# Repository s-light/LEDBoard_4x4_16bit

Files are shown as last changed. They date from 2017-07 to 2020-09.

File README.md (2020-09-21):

<!--lint disable maximum-line-length-->
<!--lint disable list-item-spacing-->
<!--lint disable list-item-indent-->

# LED-Board 4x4 16bit
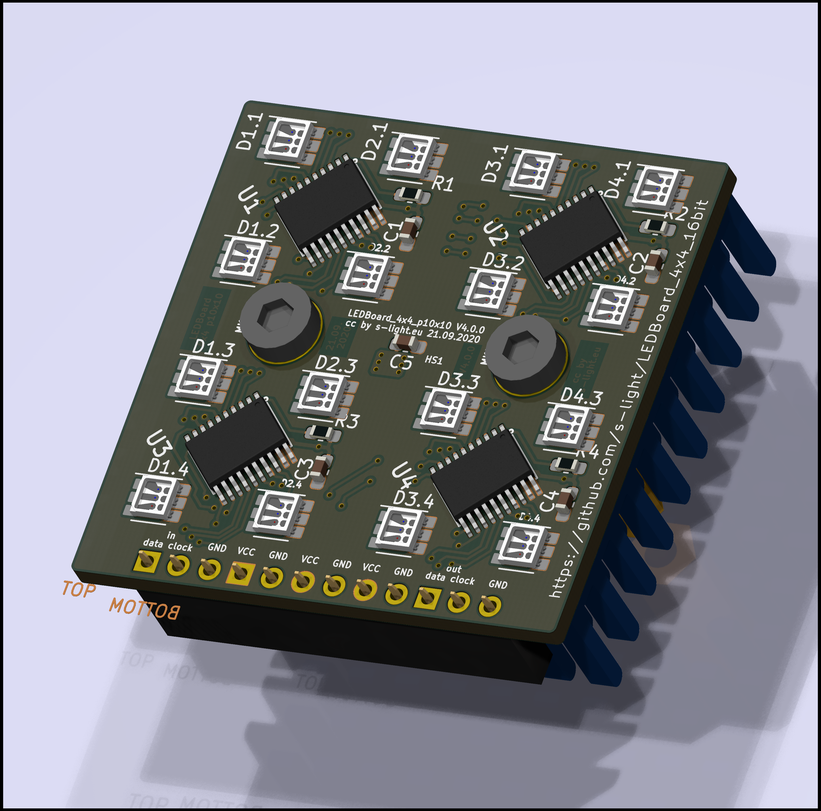
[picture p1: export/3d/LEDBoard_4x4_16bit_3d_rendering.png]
LED-Board front


a LED-Matrix Board that can be combined seamlessly to bigger areas.  
It uses the [TI TLC5971](http://www.ti.com/product/TLC5971) Constant-Current LED-Driver Chip with 16bit dimming resolution.  

The [original](https://github.com/s-light/LEDBoard_4x4_16bit/tree/Nichia_NSSM032A) LED-footprint was for [Nichia NSSM032A](http://www.nichia.co.jp/en/product/led_product_data.html?type=%27NSSM032A%27) RGB-LED.
Back in 2017 on of the brightest *low power* SMD LEDs in this size -
They are only available as full reel directly from Nichia.

so there is a [second branch](https://github.com/s-light/LEDBoard_4x4_16bit/tree/Nichia_NSSM124D) with the LED-Type changed to [Nichia NSSM124D](http://www.nichia.co.jp/en/product/led_product_data.html?type=%27NSSM124D%27) -
these are [available as cut-tape from an distributor](http://www.leds.de/en/Ordinary-LEDs/SMD-LEDs/Nichia-SMD-LED-RGB-NSSM124DT.html).

latest addition is a [branch with TLC5971*PWP* driver chips](https://github.com/s-light/LEDBoard_4x4_16bit/tree/TLC5971PWP) -
this is the same chip but in an HTSSOP-20 housing -
that is easier to solder by hand.
--> no hot air / reflow oven necessary, but recommend.

## Project-Status
- received first Batch ([Release V1.0.0](https://github.com/s-light/LEDBoard_4x4_16bit/releases/tag/v1.0))
- received second Batch ([Release V3.0.1](https://github.com/s-light/LEDBoard_4x4_16bit/tree/v3.0.1))
- 11 PCB's assembled  
  10 working :sun_with_face:  
  first solder board not working - has a short between VCC and GND (to be checked)
- all needed heavy rework: stencil has to big openings - this gives a bunch of bridges at QFN 0,5mm Pin-Pitch IC's
- had some problems with the first reflow oven used - you need enough heat from the bottom to solder correctly.
- made some picture from first assembly: [gallery](./doc/gallery.md)
- ~~fix pads that are to small for hand-soldering~~ done
- ~~order updated PCB's~~ done
- ~~solder some more boards~~ done (total: ~60)
- ~~order screws at [Wegertseder](https://www.wegertseder.com/ArticleDetails.aspx?AKNUM=2588)~~ done
- updated KiCad files to new version.

### TODO
- order Heat Sink with machining and Thermal Foil from [Fischer Elektronik](http://www.fischerelektronik.de/web_fischer/de_DE/K%C3%BChlk%C3%B6rper/B01/K%C3%BChlk%C3%B6rper%20f%C3%BCr%20PGA/PR/ICKPGA14x14x12_/$productCard/parameters/index.xht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)
- add some more mounting layouts to [LEDBoard_Layouts](https://github.com/s-light/LEDBoard_Layouts)
- take some more pictures

## Technical Information
there are groups of 4 LEDs that are controlled by one TLC5971.  
every controller chip has 12 ConstantCurrent outputs. so every LED is controllable individual.

you need to create a mapping to linearize the order:  

| X/Y | 0 | 1 | 2 | 3 |
| :---- | :--- | :--- | :--- | :--- |
| **0** | IC1 LED1 | IC1 LED2 | IC2 LED1 | IC2 LED2 |
| **1** | IC1 LED3 | IC1 LED4 | IC2 LED3 | IC2 LED4 |
| **2** | IC3 LED1 | IC3 LED2 | IC4 LED1 | IC4 LED2 |
| **3** | IC3 LED3 | IC3 LED4 | IC4 LED3 | IC4 LED4 |

example for c++ / arduino
```c++
const uint8_t channel_position_map[4][4] = {
    { 0,  1,  4,  5},
    { 2,  3,  6,  7},
    { 8,  9, 12, 13},
    {10, 11, 14, 15},
};
```

### HW
- PCB size: 40x40x18mm
- pixel-pitch: 10mm
- 3.8V..5.5V
- <= 1A (maximum)

### BOM
there is the raw exported BOM at [export/BOM/LEDBoard_4x4_16bit_BOM.csv](export/BOM/LEDBoard_4x4_16bit_BOM.csv) and an modified LibreOffice Calc file with ordering and Price calculations at [doc/LEDBoard_4x4_16bit_PriceCalculation_Ordering](doc/LEDBoard_4x4_16bit_PriceCalculation_Ordering.csv) (link points to exported csv as preview)

### controlling

#### Micro Controller / Arduino
there are some Arduino Libraries out there that can generate the correct protocol.
My Favorite is [ulrichstern/Tlc59711](https://github.com/ulrichstern/Tlc59711)

i have made a [simple arduino sketch](https://github.com/s-light/LEDBoard_4x4_16bit_HWTest) that uses the mentioned library to test the Boards during production.

#### embedded linux boards
Additionally you can use a embedded Linux board with an SPI output to drive them.
I have successfully implemented the protocol in my fork of OLA.
(TODO: Link and explain OLA setup)

there are also other python libraries out there.
(TODO: test some of theme and link here)

### power & signal connections
theoretically calculate with about 1A@5V for every Board.
Supply Voltage (VCC) should be 3,8V..5,5V - If possible use the lower end. so no extra heat is generated in the driver IC.

for the control-signal there are an input and output 3pin 2,54mm connector:
1. Data
1. Clock
1. GND

for the power there are 3x2pin 2,54mm connector positions.
so you could daisy-chain power also - but be aware the pcb-traces can handle an absolute maximum of 3,5A. So i would recommend only 1 or maximum 2 daisy-chained boards.

## KiCad Version
```text
Application: KiCad

Version: 5.99.0-unknown-652a59b78~104~ubuntu20.04.1, release build

Libraries:
	wxWidgets 3.0.4
	libcurl/7.68.0 OpenSSL/1.1.1f zlib/1.2.11 brotli/1.0.7 libidn2/2.2.0 libpsl/0.21.0 (+libidn2/2.2.0) libssh/0.9.3/openssl/zlib nghttp2/1.40.0 librtmp/2.3

Platform: Linux 5.4.0-48-generic x86_64, 64 bit, Little endian, wxGTK

Build Info:
	Date: Sep 16 2020 10:16:55
	wxWidgets: 3.0.4 (wchar_t,wx containers,compatible with 2.8) GTK+ 3.24
	Boost: 1.71.0
	OCE: 6.9.1
	Curl: 7.68.0
	ngspice: 31
	Compiler: GCC 9.3.0 with C++ ABI 1013

Build settings:
	KICAD_SCRIPTING=ON
	KICAD_SCRIPTING_MODULES=ON
	KICAD_SCRIPTING_PYTHON3=ON
	KICAD_SCRIPTING_WXPYTHON=ON
	KICAD_SCRIPTING_WXPYTHON_PHOENIX=ON
	KICAD_SCRIPTING_ACTION_MENU=ON
	BUILD_GITHUB_PLUGIN=ON
	KICAD_USE_OCE=ON
	KICAD_SPICE=ON

```

## License
<!-- License info -->
<a rel="license" href="http://creativecommons.org/licenses/by/4.0/">
    
</a><br />
<span xmlns:dct="http://purl.org/dc/terms/" property="dct:title">
    LEDBoard_4x4_16bit
</span>
by
<a xmlns:cc="http://creativecommons.org/ns#" href="https://github.com/s-light/LEDBoard_4x4_16bit" property="cc:attributionName" rel="cc:attributionURL">
    Stefan Krüger (s-light)
</a>
is licensed under a
<a rel="license" href="http://creativecommons.org/licenses/by/4.0/">
    Creative Commons Attribution 4.0 International License
</a>.

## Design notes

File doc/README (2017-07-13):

# documentation

contains Schematic and Board in SVG & PDF version.
+ additional documentation

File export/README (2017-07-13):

# export

contains gerber files and Layer-SVGs and Layer-PDFs

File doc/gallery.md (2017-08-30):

# assembly
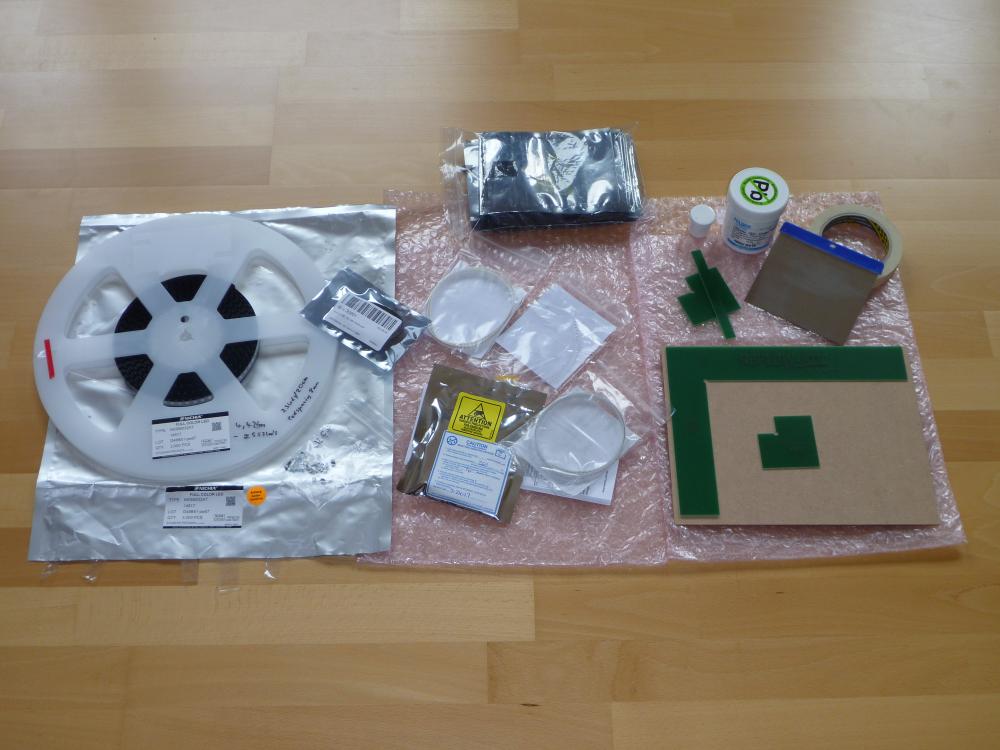
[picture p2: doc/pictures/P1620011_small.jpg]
parts

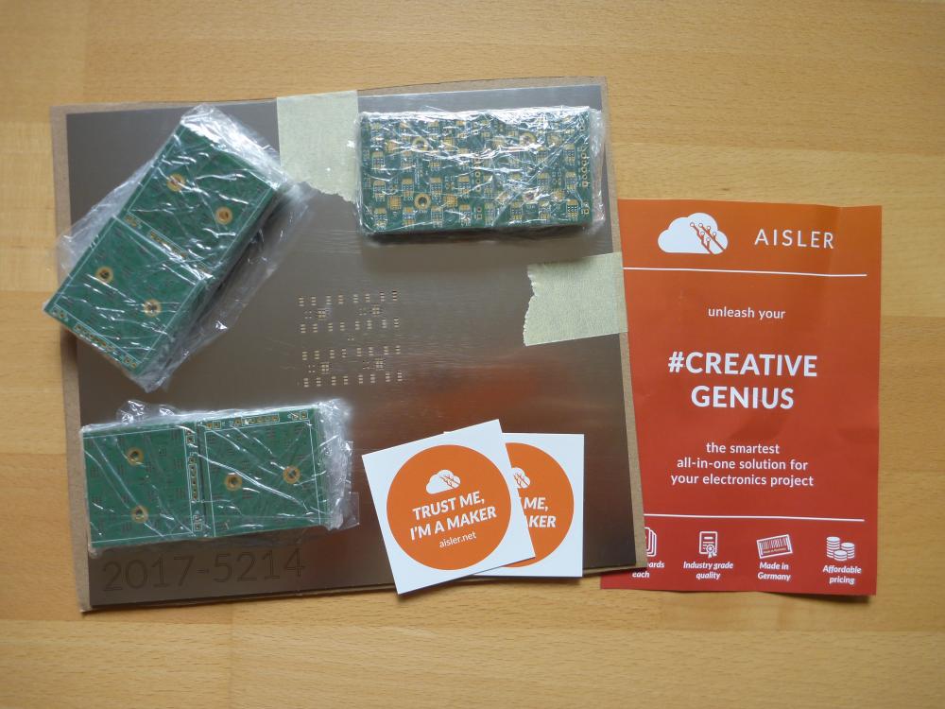
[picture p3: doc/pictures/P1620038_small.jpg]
PCBs

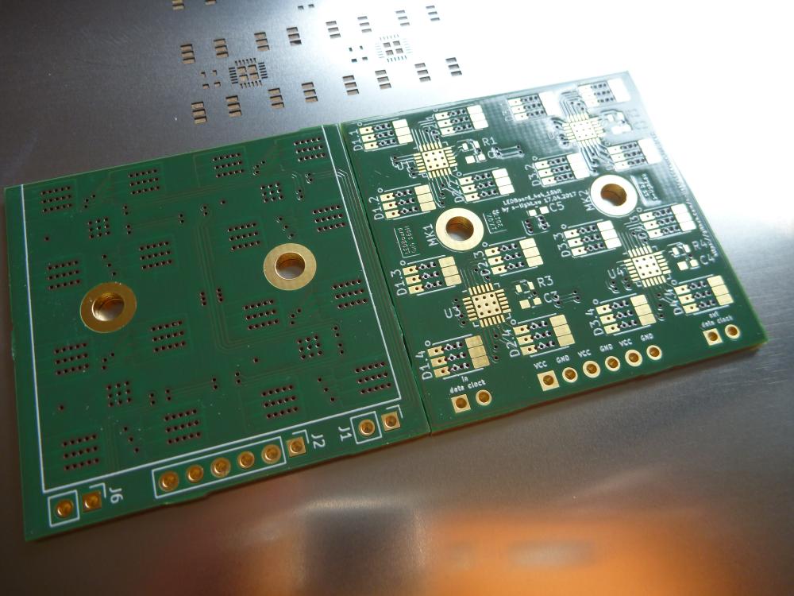
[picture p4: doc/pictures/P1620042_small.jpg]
PCBs details

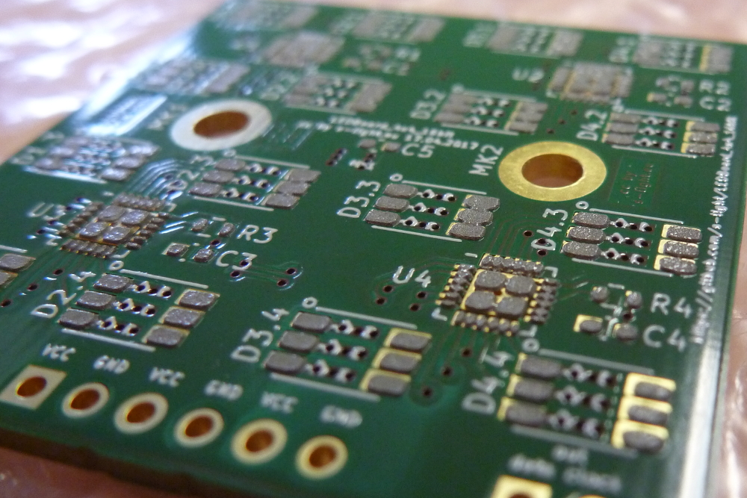
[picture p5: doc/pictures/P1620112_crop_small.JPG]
solderpaste details

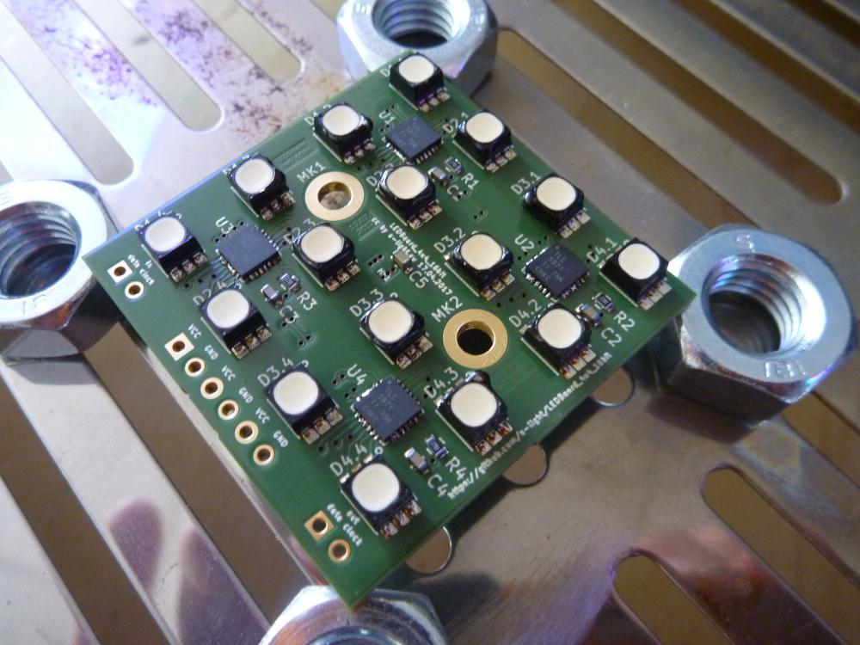
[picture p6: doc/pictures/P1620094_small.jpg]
reflow (a little hot :-(

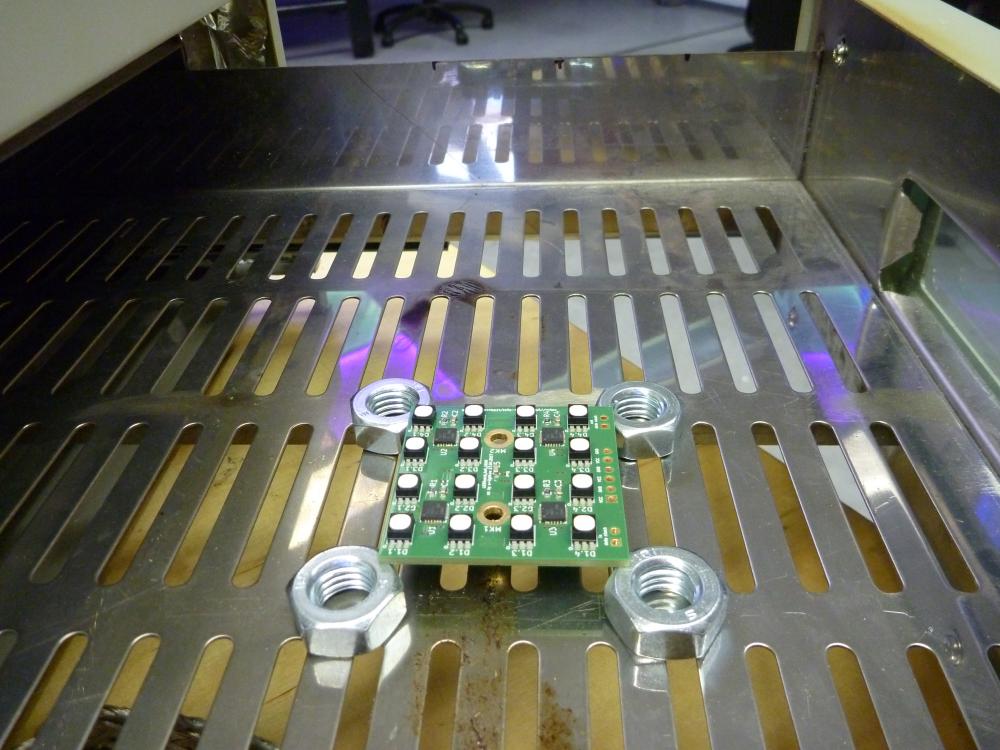
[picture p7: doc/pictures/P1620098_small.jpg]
reflow position in oven


## it works :-)
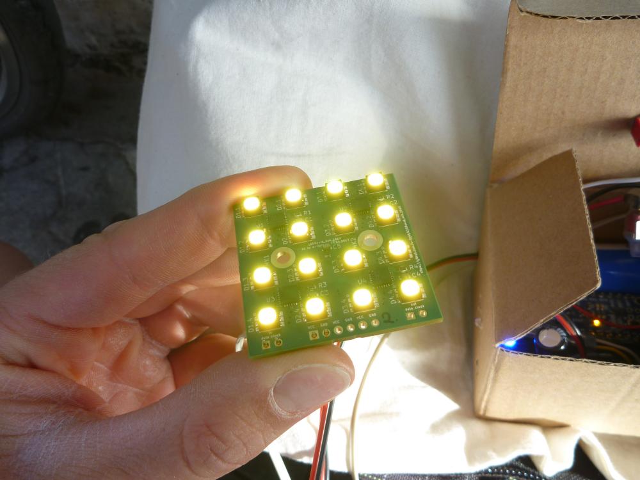
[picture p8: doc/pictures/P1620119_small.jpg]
test run yellow

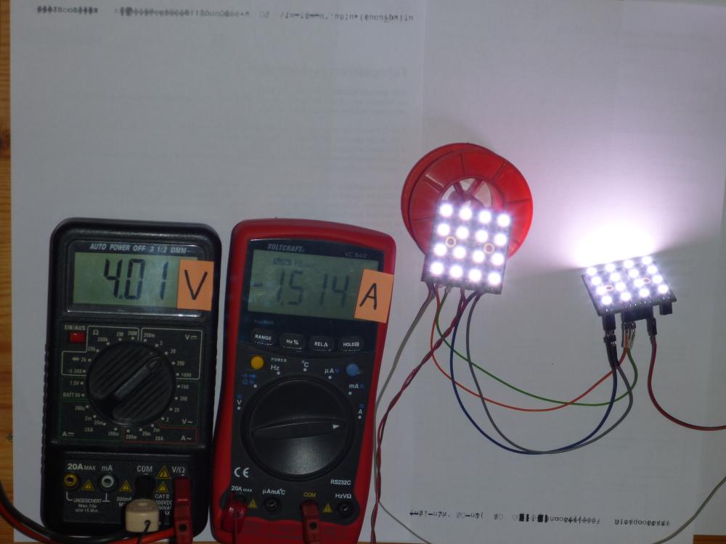
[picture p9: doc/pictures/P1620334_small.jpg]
two pcbs chained


(hover over the picture)
<style media="screen">
.specialimage {
    display: block;
    position: relative;
    z-index: 100;
}
.pic {
    display: block;
    position: absolute;
    top:0;
    left:0;
}
.specialimage .old {
    opacity: 1;
    transition: opacity 0.5s;
}
.specialimage:hover .old {
    opacity: 0;
    transition: opacity 0.5s;
}
</style>
<div class="specialimage">
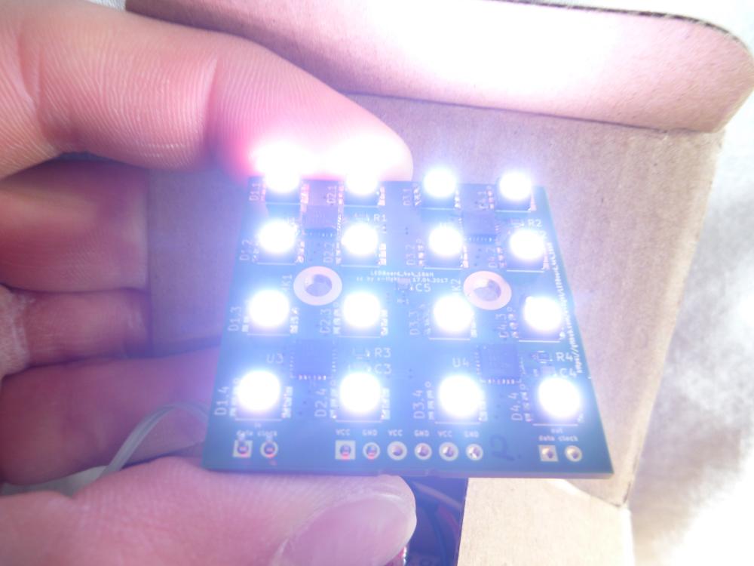
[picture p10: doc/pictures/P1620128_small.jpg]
    
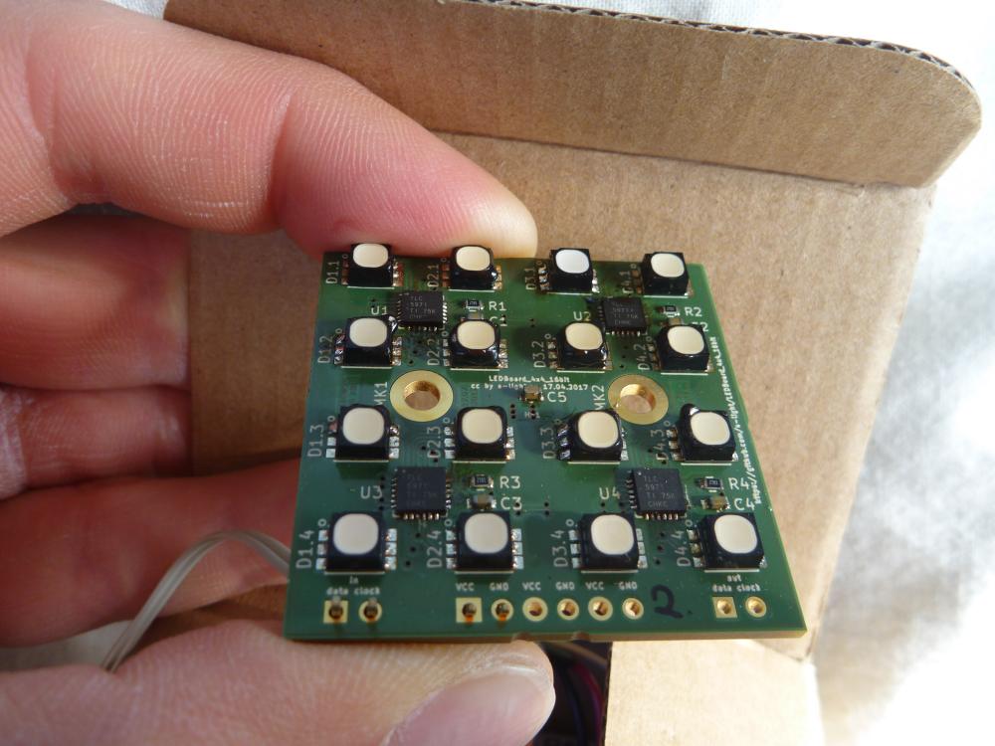
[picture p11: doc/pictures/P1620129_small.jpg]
    
</div>

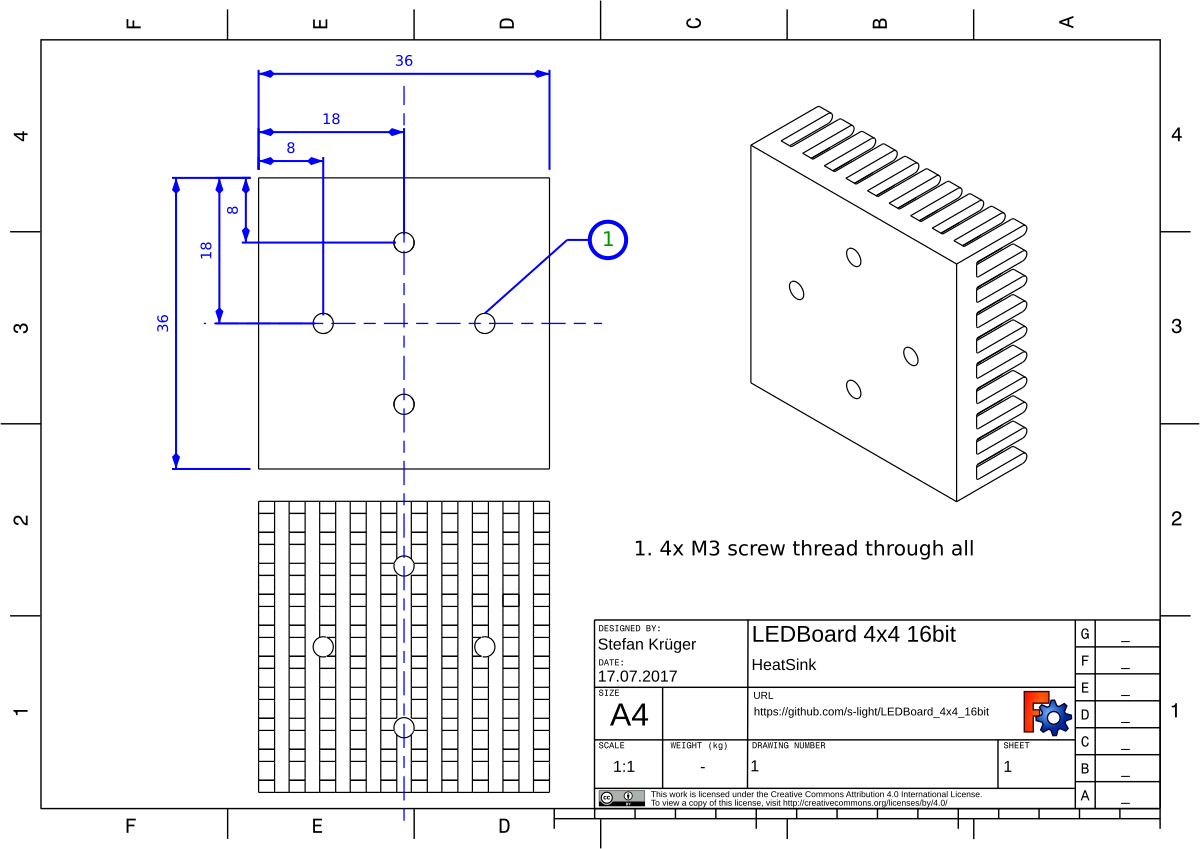
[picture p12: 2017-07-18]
parts/mechanical/HeatSink_drawing.png

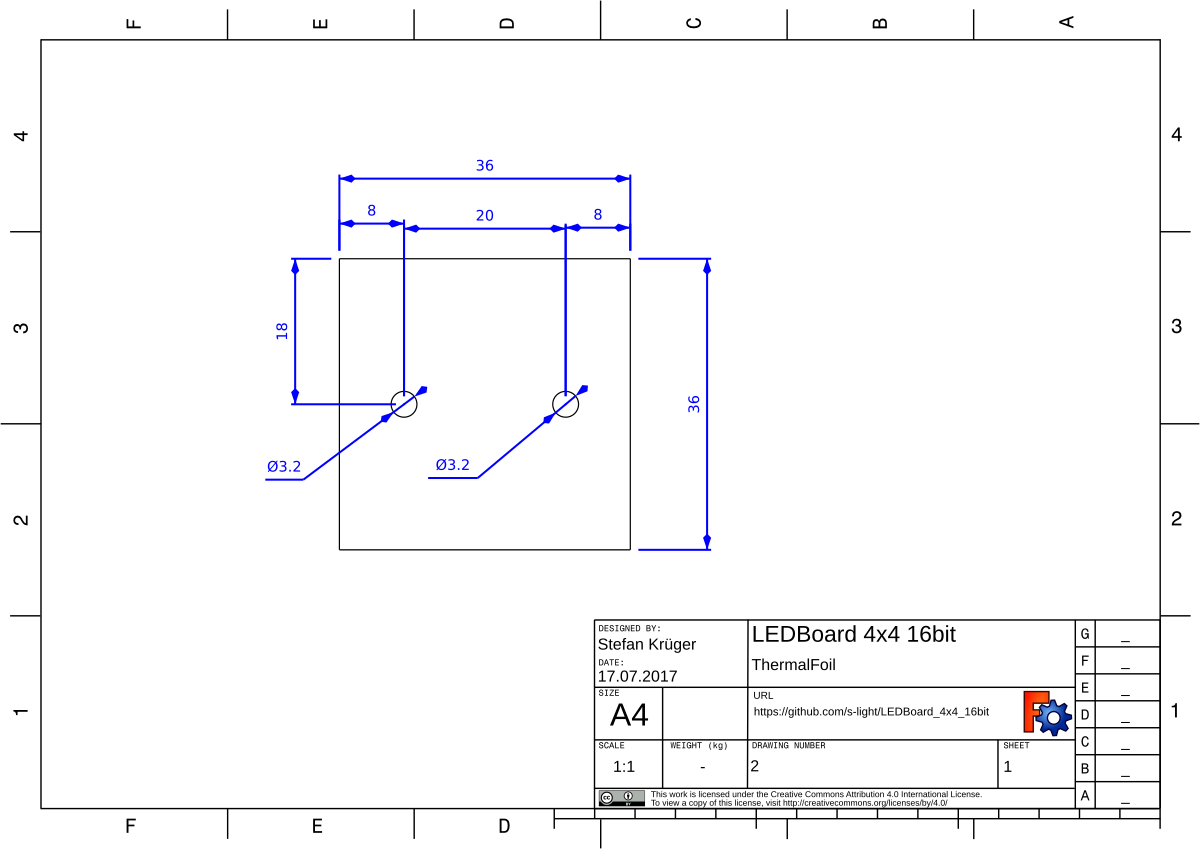
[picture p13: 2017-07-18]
parts/mechanical/ThermalFoil_drawing.png

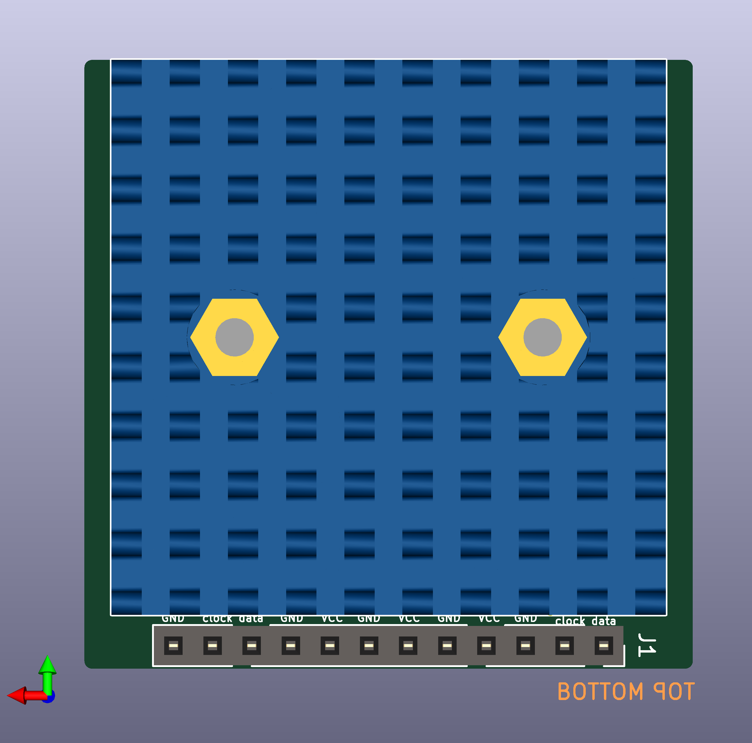
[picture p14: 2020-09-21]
export/3d/LEDBoard_4x4_16bit_back_wHeatSink.png

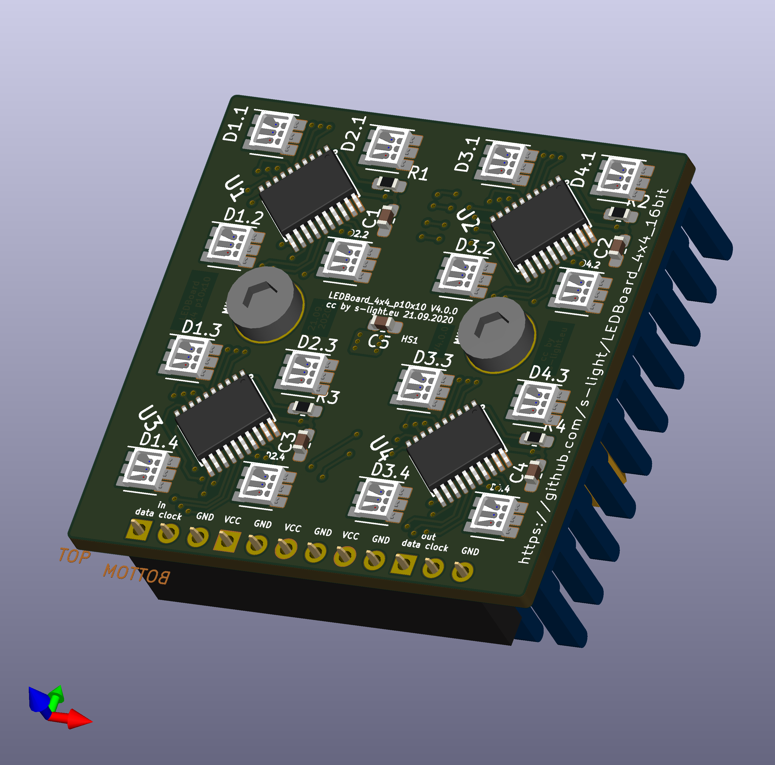
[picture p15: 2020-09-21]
export/3d/LEDBoard_4x4_16bit_3d.png

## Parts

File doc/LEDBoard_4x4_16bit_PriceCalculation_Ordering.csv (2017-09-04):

Reference | Quantity | Value | Footprint | Manufacture | Part | Manufacture URL | Distributor / shop | order number | price | Single Board Price | Min quantity For board count | package Size | Order Quantity | price sum
C1 C2 C3 C4 | 4 | 100nF | Capacitors_SMD:C_0603 | Murata | GRM188R71H104KA93D |  | mouser | 81-GRM39X104K50D | 0,019 € | 0,08 € | 12 | 1 | 15 | 0,29 €
C5 | 1 | 47uF 6.3V | Capacitors_SMD:C_0603 | Murata | ZRB18AR60J476ME01L |  | mouser | 81-ZRB18AR60J476ME1L | 0,349 € | 0,35 € | 3 | 1 | 5 | 1,75 €
D1.1 D1.2 D1.3 D1.4 D2.1 D2.2 D2.3 D2.4 D3.1 D3.2 D3.3 D3.4 D4.1 D4.2 D4.3 D4.4 | 16 | LED_1.1 .. LED_4.4 | nichia:LED_NSSM124_wViaHeatSinkBig | Nichia | NSSM124D |  | Lumitronix | 30201 | 0,890 € | 14,24 € | 48 | 1 | 50 | 44,50 €
HS1 | 1 | Heatsink | Oddities:Dummy_Empty | Fischer Elektronik | 10037097 | http://www.fischerelektronik.de/web_fischer/de_DE/K%C3%BChlk%C3%B6rper/B01/K%C3%BChlk%C3%B6rper%20f%C3%BCr%20PGA/PR/ICKPGA14x14x12_/$productCard/parameters/in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 | Fischer Elektronik | custom request | 11,600 € | 11,60 € | 3 | 39 | 3 | 34,80 €
J1 | 1 | signal_in | Socket_Strip_Straight_1x02_Pitch2.54mm | - |  |  |  |  |  | 0,00 € | 3 |  |  | 0,00 €
J2 | 1 | power | Socket_Strip_Straight_1x06_Pitch2.54mm | - |  |  |  |  |  | 0,00 € | 3 |  |  | 0,00 €
J6 | 1 | signal_out | Socket_Strip_Straight_1x02_Pitch2.54mm | - |  |  |  |  |  | 0,00 € | 3 |  |  | 0,00 €
MK1 MK2 | 2 | Mounting_Hole | MountingHole_3.2mm_M3_ISO7380_Pad | Wegertseder | 2588-408 | https://www.wegertseder.com/ArticleDetails.aspx?AKNUM=2588 | Wegerseder | 2588-408 | 0,052 € | 0,10 € | 6 | 100 | 100 | 5,24 €
R1 R2 R3 R4 | 4 | 2k7 1% | Resistors_SMD:R_0603 | Vishay | CRCW06032K70FKEB |  | mouser | 71-CRCW06032K70FKEB | 0,009 € | 0,04 € | 12 | 1 | 15 | 0,14 €
U1 U2 U3 U4 | 4 | TLC5971RGER | Housings_SSOP:HTSSOP-20-1EP_4.4x6.5mm_Pitch0.65mm_ThermalVias_TI_R-PDSO-G20 | Texas Instruments | TLC5971PWPR | http://www.ti.com/product/TLC5971/description | mouser | 595-TLC5971PWPR | 2,430 € | 9,72 € | 12 | 1 | 12 | 29,16 €
PCB | 1 | - | - | aisler.net |  | https://go.aisler.net/s-light/ledboard_4x4_16bit/main-pcb | aisler.net | - | 4,320 € | 4,32 € | 3 | 3 | 3 | 12,96 €
 |  |  |  |  |  |  |  |  |  |  | 108
 |  |  |  |  |  |  | Sum Board |  |  | 40,45 € | 121,34 € |  |  | 128,825
 |  |  |  |  |  |  | Board Count | 3
Additional Things
 |  |  |  |  | Stencil |  | aisler.net | https://go.aisler.net/s-light/ledboard_4x4_16bit/main-pcb | 11,550 € |  |  |  | 1 | 11,55 €
 |  |  |  |  | Squeegee |  | Beta-estore | RK-10009 | 1,900 € |  |  |  | 1 | 1,90 €
 |  |  |  |  | PCB Holder Set - 1.6mm thick |  | Beta-estore | RK-10007 | 4,900 € |  |  |  | 1 | 4,90 €
 |  |  |  |  | Solder paste ISO-Cream "Clear" |  | Beta-estore | RK-10753 | 23,400 € |  |  |  | 1 | 23,40 €
 |  |  |  |  |  |  |  |  |  |  |  |  | TOTAL | 170,58 €
 |  |  |  |  |  |  |  |  |  |  |  |  | Single Board | 56,86 €

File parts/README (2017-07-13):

project specific copy of used parts.
if possible as Git Submodules
see http://www.git-scm.com/book/en/v2/Git-Tools-Submodules

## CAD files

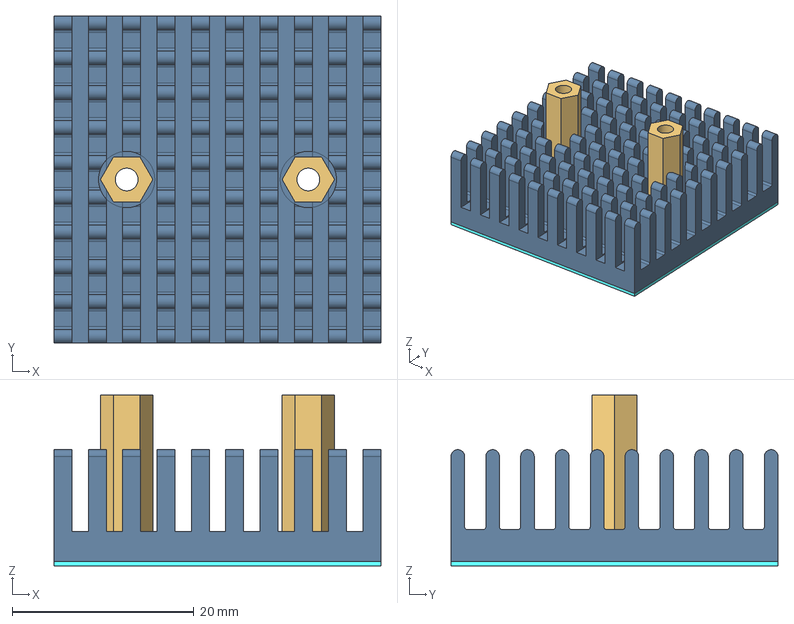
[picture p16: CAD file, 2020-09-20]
parts/mechanical/HeatSink_Assembly.step
36.0 x 36.0 x 18.8 mm
Body_Spacer_Hex_M3x15_Clone
Body_Spacer_Hex_M3x15
thermal_foil
HeatSink

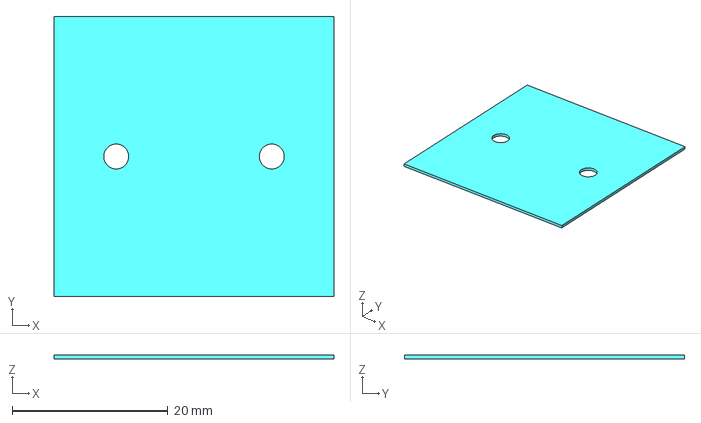
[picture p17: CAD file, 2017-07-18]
parts/mechanical/ThermalFoil.step
36.0 x 36.0 x 0.5 mm

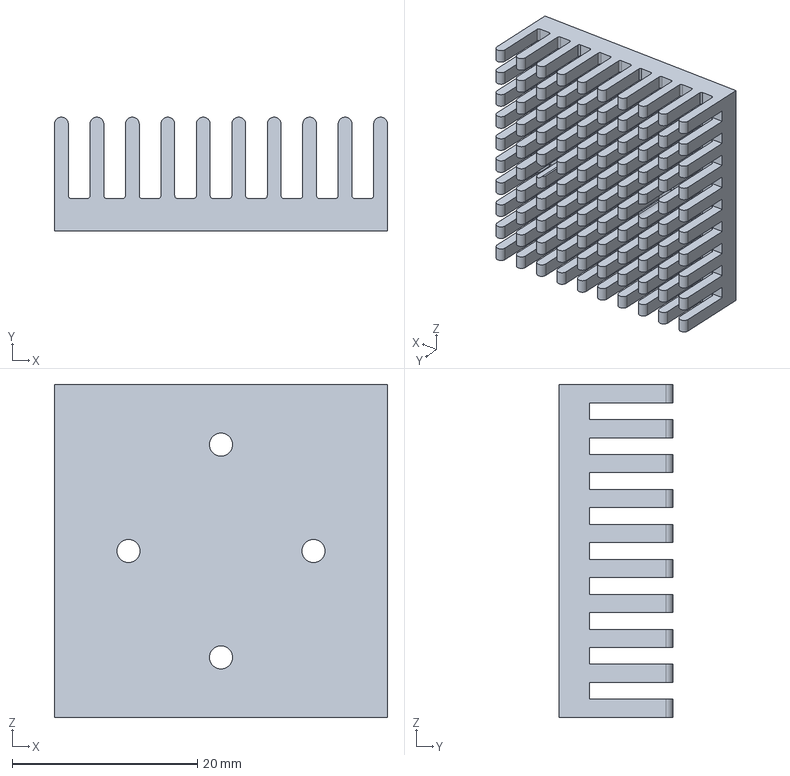
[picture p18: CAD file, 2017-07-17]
parts/mechanical/HeatSink_FischerElektronik__ICK_PGA_14_x_14_x_12.step
36.0 x 12.3 x 36.0 mm

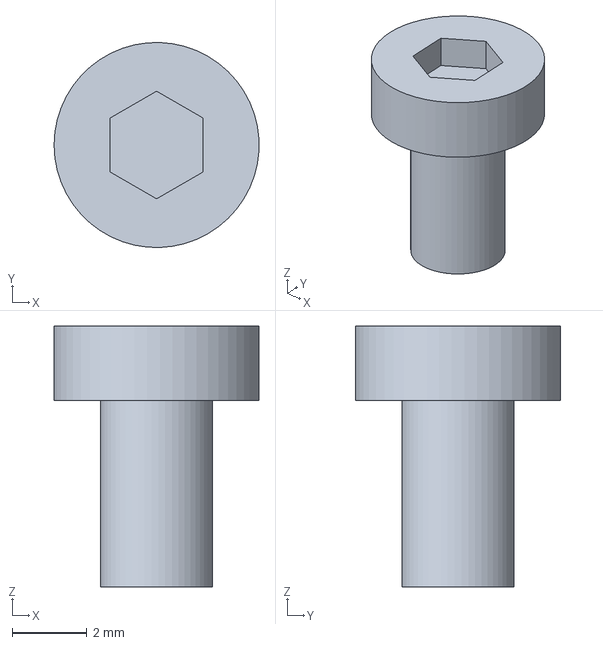
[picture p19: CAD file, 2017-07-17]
parts/mechanical/screw_M3_thinhead.step
5.49 x 5.50 x 7.00 mm

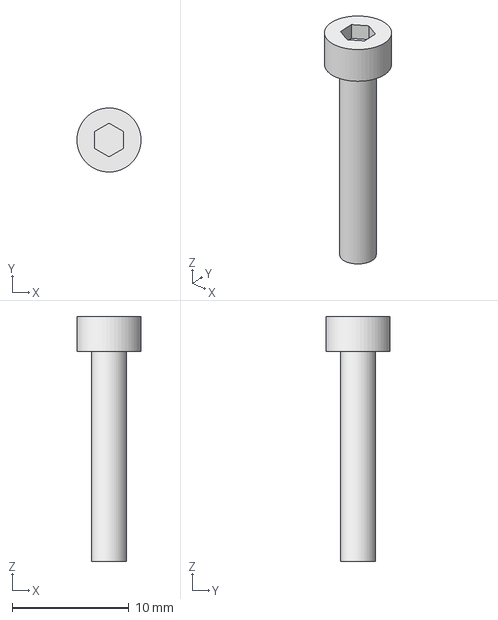
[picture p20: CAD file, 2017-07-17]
parts/mechanical/screw_M3.step
5.49 x 5.50 x 21.0 mm

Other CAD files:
doc/connector_positions.fcstd
parts/mechanical/HeatSink_FischerElektronik__ICK_PGA_14_x_14_x_12.fcstd
parts/mechanical/screw_M3.fcstd
parts/mechanical/screw_M3_thinhead.fcstd

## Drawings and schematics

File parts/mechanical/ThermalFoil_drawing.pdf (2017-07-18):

8 | 8

36

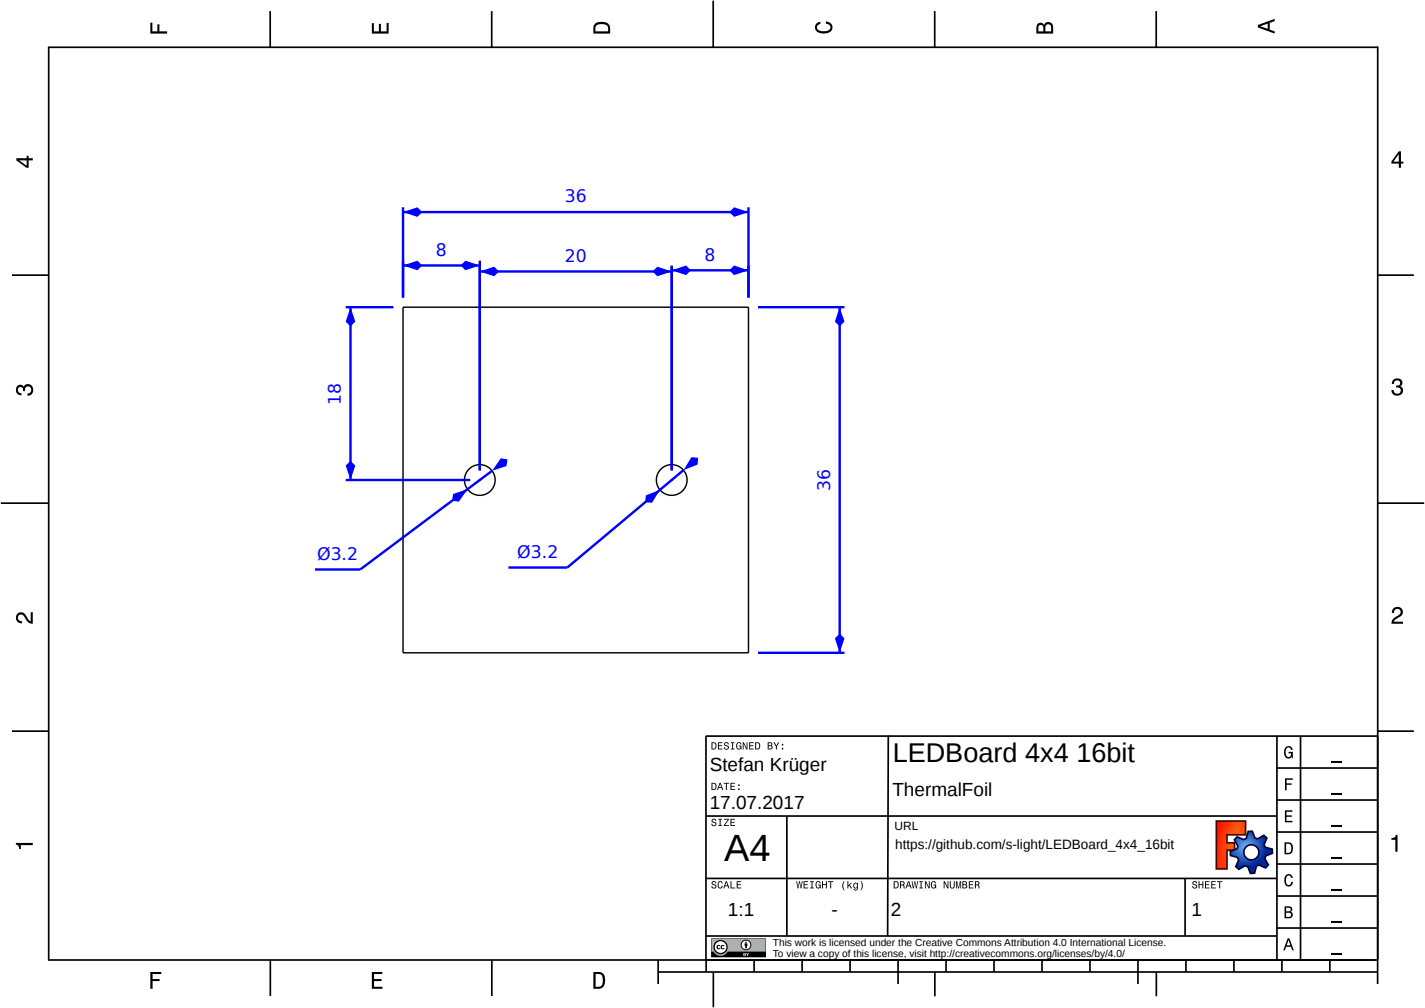
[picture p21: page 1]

Stefan Krüger 17.07.2017 | LEDBoard 4x4 16bit ThermalFoil

URL
https://github.com/s-light/LEDBoard_4x4_16bit

This work is licensed under the Creative Commons Attribution 4.0 International License.
To view a copy of this license, visit http://creativecommons.org/licenses/by/4.0/

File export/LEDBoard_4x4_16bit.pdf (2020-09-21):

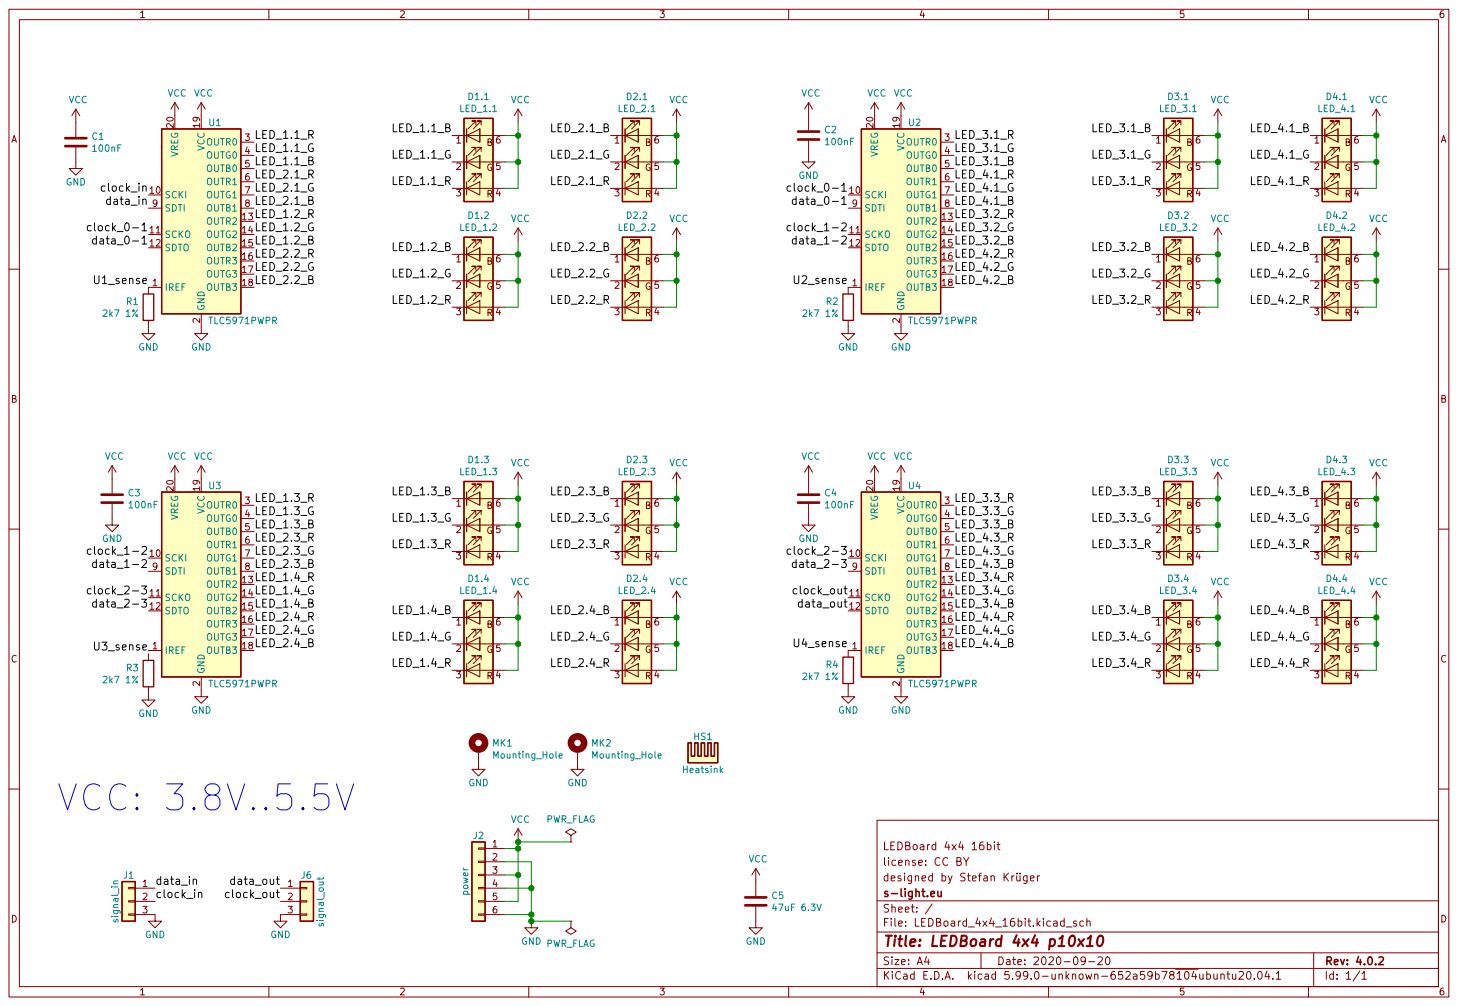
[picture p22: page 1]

VCC VCC VCC GND

license: CC BY
File: LEDBoard_4x4_16bit.kicad_sch Sheet: / s-light.eu

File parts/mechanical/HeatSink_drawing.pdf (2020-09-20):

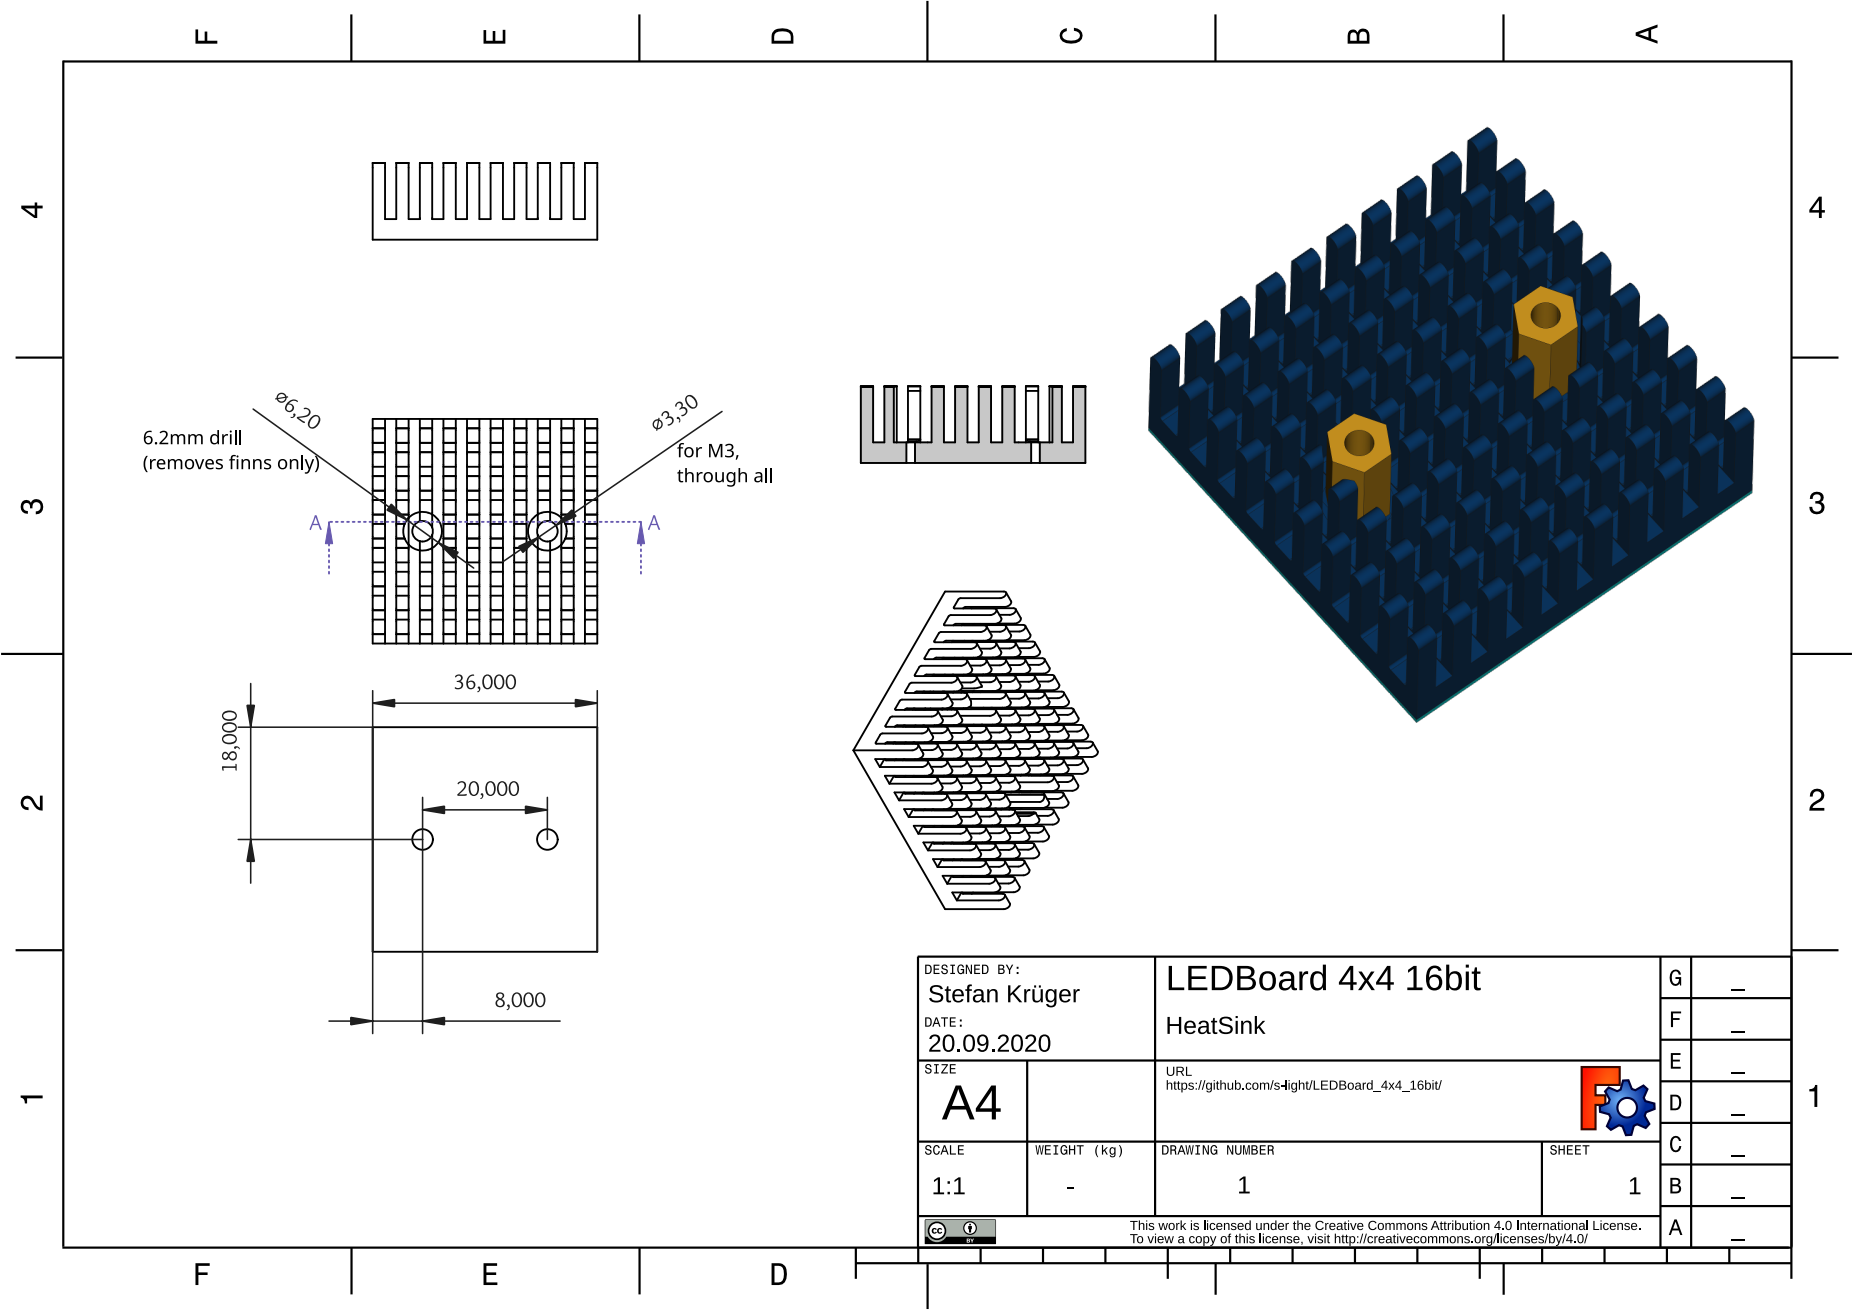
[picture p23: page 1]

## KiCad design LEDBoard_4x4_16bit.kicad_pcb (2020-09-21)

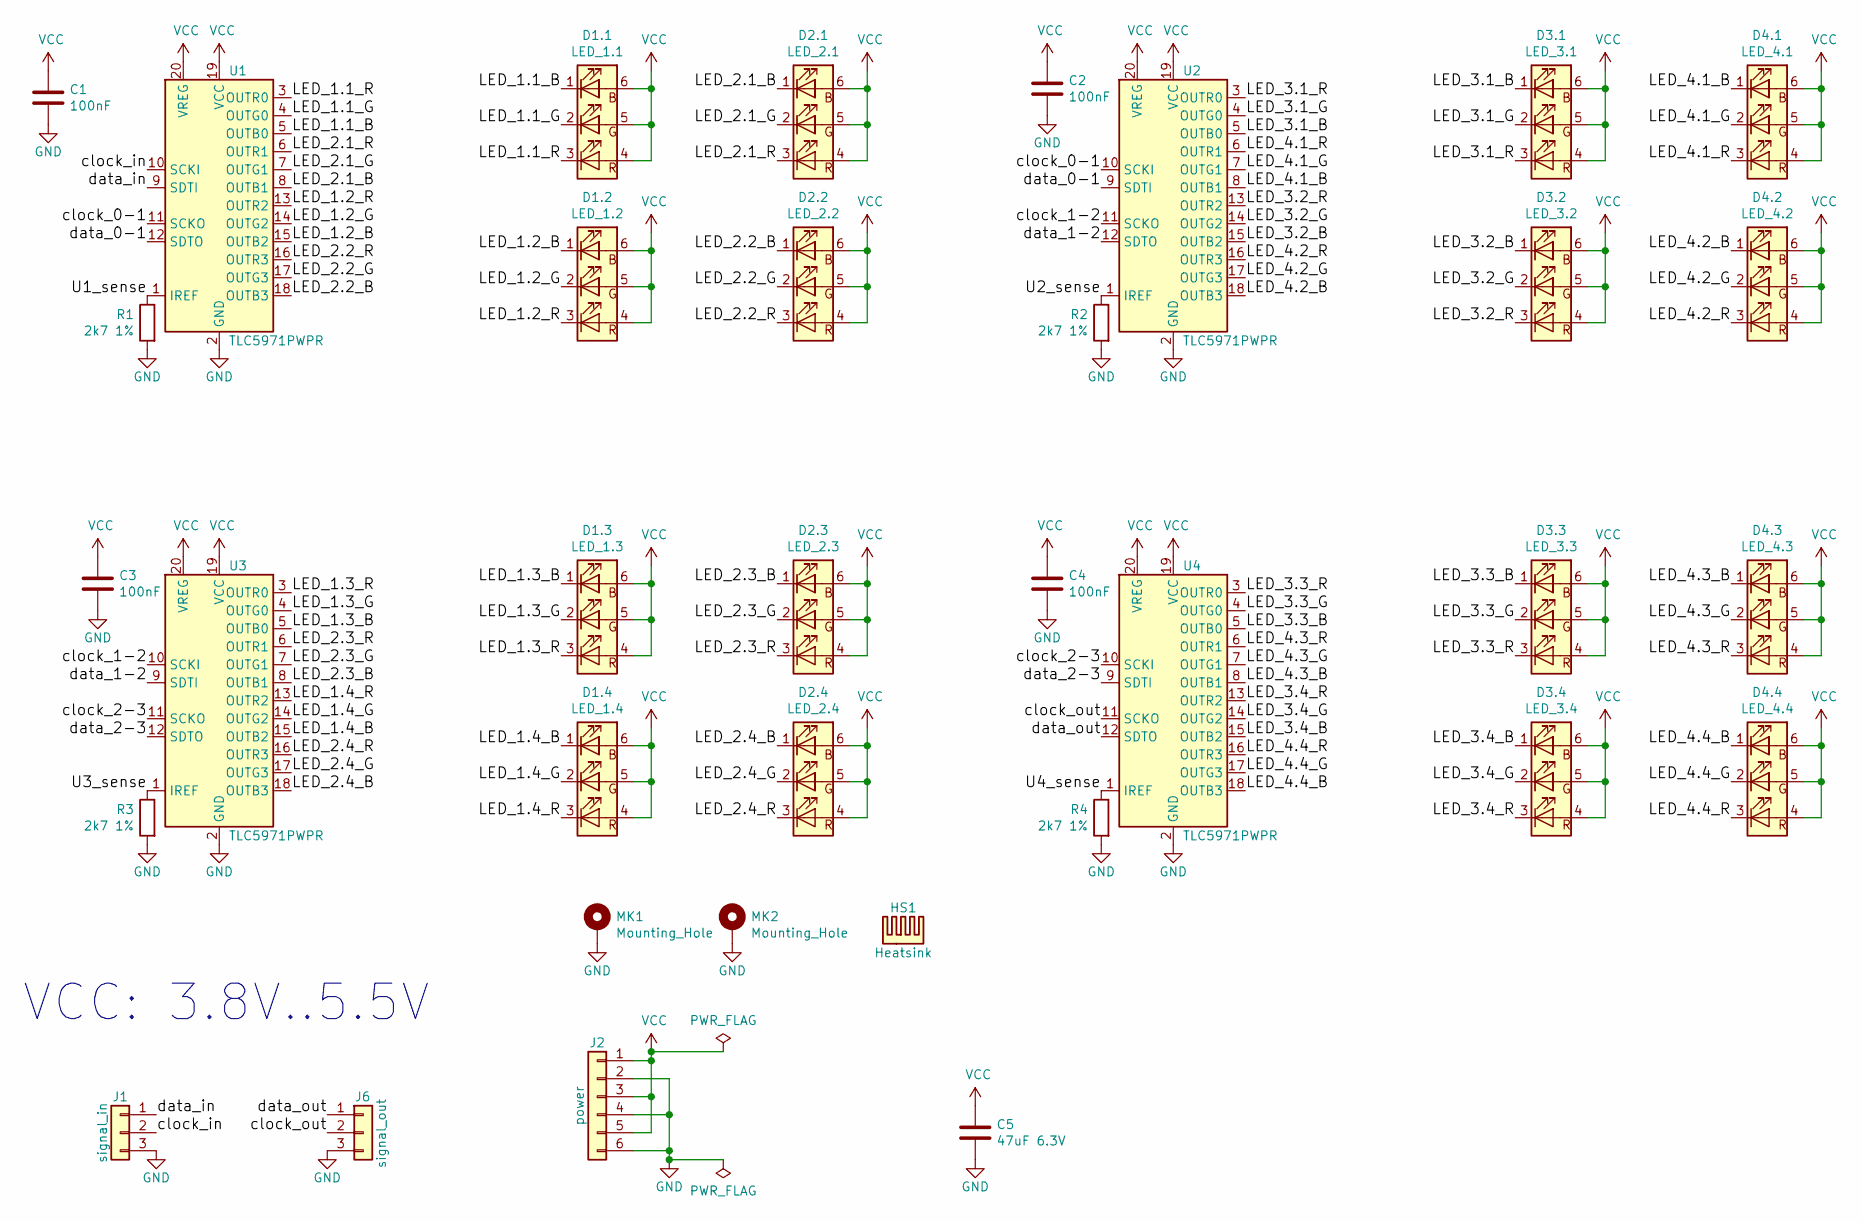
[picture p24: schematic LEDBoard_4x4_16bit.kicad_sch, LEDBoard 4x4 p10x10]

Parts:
C1, C2, C3, C4: 100nF; C_0603_HandSoldering; mouser 81-GRM39X104K50D
C5: 47uF 6.3V; C_0603_HandSoldering; mouser 81-GRM188R60J476ME5D
D1.1: LED_1.1; LED_NSSM124_wViaHeatSinkBig_roundedPads
D1.2: LED_1.2; LED_NSSM124_wViaHeatSinkBig_roundedPads
D1.3: LED_1.3; LED_NSSM124_wViaHeatSinkBig_roundedPads
D1.4: LED_1.4; LED_NSSM124_wViaHeatSinkBig_roundedPads
D2.1: LED_2.1; LED_NSSM124_wViaHeatSinkBig_roundedPads
D2.2: LED_2.2; LED_NSSM124_wViaHeatSinkBig_roundedPads
D2.3: LED_2.3; LED_NSSM124_wViaHeatSinkBig_roundedPads
D2.4: LED_2.4; LED_NSSM124_wViaHeatSinkBig_roundedPads
D3.1: LED_3.1; LED_NSSM124_wViaHeatSinkBig_roundedPads
D3.2: LED_3.2; LED_NSSM124_wViaHeatSinkBig_roundedPads
D3.3: LED_3.3; LED_NSSM124_wViaHeatSinkBig_roundedPads
D3.4: LED_3.4; LED_NSSM124_wViaHeatSinkBig_roundedPads
D4.1: LED_4.1; LED_NSSM124_wViaHeatSinkBig_roundedPads
D4.2: LED_4.2; LED_NSSM124_wViaHeatSinkBig_roundedPads
D4.3: LED_4.3; LED_NSSM124_wViaHeatSinkBig_roundedPads
D4.4: LED_4.4; LED_NSSM124_wViaHeatSinkBig_roundedPads
HS1: Heatsink; Dummy_Empty
J1: signal_in; Socket_Strip_Straight_1x03_Pitch2.54mm
J2: power; Socket_Strip_Straight_1x06_Pitch2.54mm
J6: signal_out; Socket_Strip_Straight_1x03_Pitch2.54mm
MK1, MK2: Mounting_Hole; MountingHole_3.2mm_M3_ISO7380_Pad
R1, R2, R3, R4: 2k7 1%; R_0603_HandSoldering; mouser 71-CRCW06032K70FKEB
U1, U2, U4: TLC5971PWPR; HTSSOP-20-1EP_4.4x6.5mm_P0.65mm_EP3.4x6.5mm_Mask2.75x3.43mm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; mouser 595-TLC5971PWPR
U3: TLC5971PWPR; HTSSOP-20-1EP_4.4x6.5mm_Pitch0.65mm_ThermalVias_TI_R-PDSO-G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; mouser 595-TLC5971PWPR

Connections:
/LED_1.1_B: D1.1.1 (RK), U1.5 (OUTB0)
/LED_1.1_G: D1.1.2 (GK), U1.4 (OUTG0)
/LED_1.1_R: D1.1.3 (BK), U1.3 (OUTR0)
/LED_1.2_B: D1.2.1 (RK), U1.15 (OUTB2)
/LED_1.2_G: D1.2.2 (GK), U1.14 (OUTG2)
/LED_1.2_R: D1.2.3 (BK), U1.13 (OUTR2)
/LED_1.3_B: D1.3.1 (RK), U3.5 (OUTB0)
/LED_1.3_G: D1.3.2 (GK), U3.4 (OUTG0)
/LED_1.3_R: D1.3.3 (BK), U3.3 (OUTR0)
/LED_1.4_B: D1.4.1 (RK), U3.15 (OUTB2)
/LED_1.4_G: D1.4.2 (GK), U3.14 (OUTG2)
/LED_1.4_R: D1.4.3 (BK), U3.13 (OUTR2)
/LED_2.1_B: D2.1.1 (RK), U1.8 (OUTB1)
/LED_2.1_G: D2.1.2 (GK), U1.7 (OUTG1)
/LED_2.1_R: D2.1.3 (BK), U1.6 (OUTR1)
/LED_2.2_B: D2.2.1 (RK), U1.18 (OUTB3)
/LED_2.2_G: D2.2.2 (GK), U1.17 (OUTG3)
/LED_2.2_R: D2.2.3 (BK), U1.16 (OUTR3)
/LED_2.3_B: D2.3.1 (RK), U3.8 (OUTB1)
/LED_2.3_G: D2.3.2 (GK), U3.7 (OUTG1)
/LED_2.3_R: D2.3.3 (BK), U3.6 (OUTR1)
/LED_2.4_B: D2.4.1 (RK), U3.18 (OUTB3)
/LED_2.4_G: D2.4.2 (GK), U3.17 (OUTG3)
/LED_2.4_R: D2.4.3 (BK), U3.16 (OUTR3)
/LED_3.1_B: D3.1.1 (RK), U2.5 (OUTB0)
/LED_3.1_G: D3.1.2 (GK), U2.4 (OUTG0)
/LED_3.1_R: D3.1.3 (BK), U2.3 (OUTR0)
/LED_3.2_B: D3.2.1 (RK), U2.15 (OUTB2)
/LED_3.2_G: D3.2.2 (GK), U2.14 (OUTG2)
/LED_3.2_R: D3.2.3 (BK), U2.13 (OUTR2)
/LED_3.3_B: D3.3.1 (RK), U4.5 (OUTB0)
/LED_3.3_G: D3.3.2 (GK), U4.4 (OUTG0)
/LED_3.3_R: D3.3.3 (BK), U4.3 (OUTR0)
/LED_3.4_B: D3.4.1 (RK), U4.15 (OUTB2)
/LED_3.4_G: D3.4.2 (GK), U4.14 (OUTG2)
/LED_3.4_R: D3.4.3 (BK), U4.13 (OUTR2)
/LED_4.1_B: D4.1.1 (RK), U2.8 (OUTB1)
/LED_4.1_G: D4.1.2 (GK), U2.7 (OUTG1)
/LED_4.1_R: D4.1.3 (BK), U2.6 (OUTR1)
/LED_4.2_B: D4.2.1 (RK), U2.18 (OUTB3)
/LED_4.2_G: D4.2.2 (GK), U2.17 (OUTG3)
/LED_4.2_R: D4.2.3 (BK), U2.16 (OUTR3)
/LED_4.3_B: D4.3.1 (RK), U4.8 (OUTB1)
/LED_4.3_G: D4.3.2 (GK), U4.7 (OUTG1)
/LED_4.3_R: D4.3.3 (BK), U4.6 (OUTR1)
/LED_4.4_B: D4.4.1 (RK), U4.18 (OUTB3)
/LED_4.4_G: D4.4.2 (GK), U4.17 (OUTG3)
/LED_4.4_R: D4.4.3 (BK), U4.16 (OUTR3)
/U1_sense: R1.1, U1.1 (IREF)
/U2_sense: R2.1, U2.1 (IREF)
/U3_sense: R3.1, U3.1 (IREF)
/U4_sense: R4.1, U4.1 (IREF)
/clock_0-1: U1.11 (SCKO), U2.10 (SCKI)
/clock_1-2: U2.11 (SCKO), U3.10 (SCKI)
/clock_2-3: U3.11 (SCKO), U4.10 (SCKI)
/clock_in: J1.2, U1.10 (SCKI)
/clock_out: J6.2, U4.11 (SCKO)
/data_0-1: U1.12 (SDTO), U2.9 (SDTI)
/data_1-2: U2.12 (SDTO), U3.9 (SDTI)
/data_2-3: U3.12 (SDTO), U4.9 (SDTI)
/data_in: J1.1, U1.9 (SDTI)
/data_out: J6.1, U4.12 (SDTO)
GND: C1.2, C2.2, C3.2, C4.2, C5.2, J1.3, J2.2, J2.4, J2.6, J6.3, MK1.1, MK2.1, R1.2, R2.2, R3.2, R4.2, U1.2 (GND), U1.21 (GND), U2.2 (GND), U2.21 (GND), U3.2 (GND), U3.21 (GND), U4.2 (GND), U4.21 (GND)
VCC: C1.1, C2.1, C3.1, C4.1, C5.1, D1.1.4 (BA), D1.1.5 (GA), D1.1.6 (RA), D1.2.4 (BA), D1.2.5 (GA), D1.2.6 (RA), D1.3.4 (BA), D1.3.5 (GA), D1.3.6 (RA), D1.4.4 (BA), D1.4.5 (GA), D1.4.6 (RA), D2.1.4 (BA), D2.1.5 (GA), D2.1.6 (RA), D2.2.4 (BA), D2.2.5 (GA), D2.2.6 (RA), D2.3.4 (BA), D2.3.5 (GA), D2.3.6 (RA), D2.4.4 (BA), D2.4.5 (GA), D2.4.6 (RA), D3.1.4 (BA), D3.1.5 (GA), D3.1.6 (RA), D3.2.4 (BA), D3.2.5 (GA), D3.2.6 (RA), D3.3.4 (BA), D3.3.5 (GA), D3.3.6 (RA), D3.4.4 (BA), D3.4.5 (GA), D3.4.6 (RA), D4.1.4 (BA), D4.1.5 (GA), D4.1.6 (RA), D4.2.4 (BA), D4.2.5 (GA), D4.2.6 (RA), D4.3.4 (BA), D4.3.5 (GA), D4.3.6 (RA), D4.4.4 (BA), D4.4.5 (GA), D4.4.6 (RA), J2.1, J2.3, J2.5, U1.19 (VCC), U1.20 (VREG), U2.19 (VCC), U2.20 (VREG), U3.19 (VCC), U3.20 (VREG), U4.19 (VCC), U4.20 (VREG)

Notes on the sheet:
VCC: 3.8V..5.5V

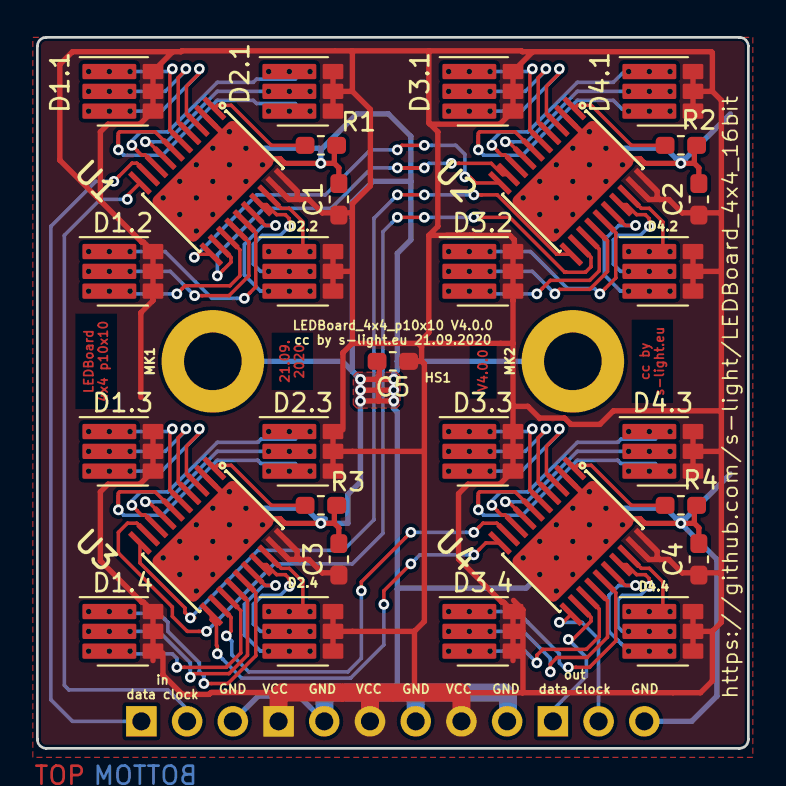
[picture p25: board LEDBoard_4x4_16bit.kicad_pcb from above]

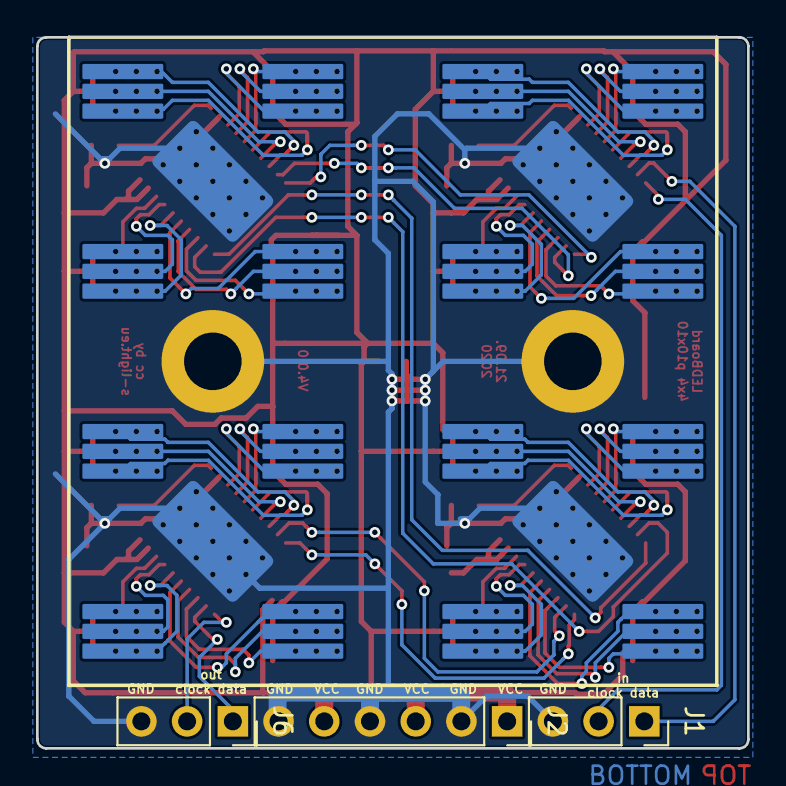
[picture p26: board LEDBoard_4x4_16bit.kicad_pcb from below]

Board: 2 copper layers, 39.5 x 39.5 mm, 35 parts (4 on the bottom side), 64 nets.

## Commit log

2017-07-13 added schematic + basic pcb layout
    [Calculations_TLC5971.ods, LEDBoard_4x4_16bit.kicad_pcb, LEDBoard_4x4_16bit.sch]
2017-07-16 pcb parts all positioned
    [LEDBoard_4x4_16bit.kicad_pcb, LEDBoard_4x4_16bit.sch, connector_positions.fcstd]
2017-07-17 pcb started routing
    [LEDBoard_4x4_16bit.kicad_pcb, LEDBoard_4x4_16bit.sch, screw_M3.fcstd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]
2017-07-17 pcb routing almost finished
    [LEDBoard_4x4_16bit.kicad_pcb, LEDBoard_4x4_16bit.sch]
2017-07-17 pcb tried to fix missing net links
    [LEDBoard_4x4_16bit.kicad_pcb, LEDBoard_4x4_16bit.sch]
2017-07-17 updated net labeling
    [LEDBoard_4x4_16bit.sch]
2017-07-17 pcb fixed broken net data_2-3
    [LEDBoard_4x4_16bit.kicad_pcb]
2017-07-17 fixed net data_1-2 (manually hand edited net-file)
    [LEDBoard_4x4_16bit.kicad_pcb, LEDBoard_4x4_16bit.sch]
2017-07-17 fixed screw 3D-model
    [screw_M3_ThinHead.fcstd, screw_M3_thinhead.fcstd, screw_M3_thinhead.step]
2017-07-17 pcb added heatsink 3d model
    [HeatSink_FischerElektronik__ICK_PGA_14_x_14_x_12.fcstd, HeatSink_FischerElektronik__ICK_PGA_14_x_14_x_12.step, LEDBoard_4x4_16bit.kicad_pcb]
2017-07-17 pcb generated images backside
2017-07-17 pcb updated page title block
    [LEDBoard_4x4_16bit.kicad_pcb]
2017-07-17 README update added * Project-Status * Technical Information * description * HW * controlling * power / signal connections * KiCad Version
2017-07-18 pcb exported gerber
    [LEDBoard_4x4_16bit-B.CrtYd.gbr, LEDBoard_4x4_16bit-B.Cu.gbl, LEDBoard_4x4_16bit-B.Fab.gbr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]
2017-07-18 pcb updated gerber files to work with go.aisler.net
    [LEDBoard_4x4_16bit-B.CrtYd.gbr, LEDBoard_4x4_16bit-B.Cu.gbl, LEDBoard_4x4_16bit-B.Fab.gbr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]
2017-07-18 drawing for mechanical parts created
    [HeatSink.step, HeatSink_FischerElektronik__ICK_PGA_14_x_14_x_12.fcstd, ThermalFoil.step]
2017-07-31 updated things
    [LEDBoard_4x4_16bit.kicad_pcb, LEDBoard_4x4_16bit.sch]
2017-07-31 updated gerber files
    [LEDBoard_4x4_16bit-B.Cu.gbl, LEDBoard_4x4_16bit-B.Mask.gbs, LEDBoard_4x4_16bit-B.Paste.gbp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]
2017-07-31 :memo: added BOM & Price/Ordering Calculations
    [LEDBoard_4x4_16bit.csv, LEDBoard_4x4_16bit_PriceCalculation_Ordering.csv, LEDBoard_4x4_16bit_PriceCalculation_Ordering.ods]
2017-07-31 added assembly image gallery
2017-08-02 :memo: hopefully fixed csv file
    [LEDBoard_4x4_16bit.csv]
2017-08-02 :memo: regenerate csv now text should be quoted so it can be interpreted by github for rendering :-)
    [LEDBoard_4x4_16bit.csv, LEDBoard_4x4_16bit_BOM.csv]
2017-08-02 :memo: added missing part numbers mostly to get a consisten row count in the exported BOM csv file
    [LEDBoard_4x4_16bit.sch, LEDBoard_4x4_16bit_BOM.csv]
2017-08-03 schematic: changed signal in & signal out to 3pin connector
    [LEDBoard_4x4_16bit.sch]
2017-08-03 :memo: fixed netlist manually removed buggy double pin 6 entries
2017-08-03 updated pcb to use new connector layout
    [LEDBoard_4x4_16bit.kicad_pcb]
2017-08-03 generated gerber files
    [LEDBoard_4x4_16bit-B.Cu.gbl, LEDBoard_4x4_16bit-B.Mask.gbs, LEDBoard_4x4_16bit-B.Paste.gbp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]
2017-08-03 updated version info in pcb
    [LEDBoard_4x4_16bit.kicad_pcb]
2017-08-03 pcb fixed comment
    [LEDBoard_4x4_16bit.kicad_pcb]
2017-08-08 pcb: changed size and corners. size: to allow for 0,5mm tolerance corners: minimal radius 0,5mm
    [LEDBoard_4x4_16bit.kicad_pcb]
2017-08-08 added soldering profile info (combined from the nichia and Felder datasheets)
2017-08-08 schematic: updated LED-Type to NSSM124D + generated BOM + exported NET-List + modified it (changed buggy nets)
    [LEDBoard_4x4_16bit.sch, LEDBoard_4x4_16bit_BOM.csv]
2017-08-09 updated pcb to LED-Type NSSM124D
    [LEDBoard_4x4_16bit.kicad_pcb]
2017-08-09 pcb updated renderings
    [LEDBoard_4x4_16bit.kicad_pcb]
2017-08-09 updated exports
    [LEDBoard_4x4_16bit-B.Cu.gbl, LEDBoard_4x4_16bit-B.Mask.gbs, LEDBoard_4x4_16bit-B.Paste.gbp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]
2017-08-09 pcb footprints: updated 3D-Models to use step
    [LEDBoard_4x4_16bit.kicad_pcb]
2017-08-30 :rainbow: added image with two pcbs working
2017-08-30 started to do variant with TLC5971PWP --> HTSSOP housing
    [LEDBoard_4x4_16bit.kicad_pcb, LEDBoard_4x4_16bit.sch]
2017-08-31 preparation for new housings
    [LEDBoard_4x4_16bit.kicad_pcb, LEDBoard_4x4_16bit.sch]
2017-08-31 updated driver housings + reroute
    [LEDBoard_4x4_16bit.kicad_pcb]
2017-08-31 updated BOM
    [LEDBoard_4x4_16bit.sch, LEDBoard_4x4_16bit_BOM.csv]
2017-08-31 updated exports and images
    [LEDBoard_4x4_16bit-B.Cu.gbl, LEDBoard_4x4_16bit-B.Mask.gbs, LEDBoard_4x4_16bit-B.Paste.gbp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]
2017-09-04 pcb: temporary remove layer-alignment-target
    [LEDBoard_4x4_16bit.kicad_pcb]
2017-09-04 updated PriceCalculation
    [LEDBoard_4x4_16bit_PriceCalculation_Ordering.csv, LEDBoard_4x4_16bit_PriceCalculation_Ordering.ods]
2017-09-27 updated smd pads to roundedrect version
    [LEDBoard_4x4_16bit-B.Cu.gbl, LEDBoard_4x4_16bit-B.Mask.gbs, LEDBoard_4x4_16bit-B.Paste.gbp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]
2017-12-16 updated schematic to new file format
    [LEDBoard_4x4_16bit.sch]
2017-12-16 updated Resistors and Capacitors for easier handsoldering
    [LEDBoard_4x4_16bit.kicad_pcb, LEDBoard_4x4_16bit.sch]
2020-09-20 update HeatSink infos
    (cherry picked from commit 1320d880c5138aec875839203008c73e6e43c43f)
    [HeatSink_Assembly.step, HeatSink_FischerElektronik__ICK_PGA_14_x_14_x_12.fcstd]
2020-09-21 update Schematics & PCB to - kicad nightliy 599 - use current default librarie symbols and footprints - create renderings
    [HeatSink.step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]

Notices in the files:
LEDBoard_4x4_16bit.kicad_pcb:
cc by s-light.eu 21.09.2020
